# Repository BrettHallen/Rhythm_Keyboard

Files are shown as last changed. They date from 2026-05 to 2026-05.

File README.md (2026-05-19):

# Ритм Клавиатура<br>Rhythm Keyboard
Mystery post-Soviet (1992) КР80ВМ80А (Intel 8080) based machine.<br>

It has 2KB of RAM (КР537РУ10, like HM6516-9) and 6KB of ROM (three КС573РФ2, like 2716).<br>

There doesn't appear to be any factory or design marking that I've found so far.  The case is metal and is possibly custom made.  There is an expansion interface (СНП58-64, like DIN 41612) but there is no access from outside the case.<br>

It has a 5-pin DIN socket for what we assume is a cassette (магнитофон) and a very long 9-wire cable that has been cut, perhaps from some larger device that it controlled and was not possible to move.<br>

The main chips are:<br>
- КР580ВМ80А (Intel 8080A CPU)
- КР580ВВ51А  (Intel 8251 USART)
- КР580ГФ24 (Intel 8224 clock generator/driver)
- КР580ВИ53 (Intel 8253 PIT)
- 2 x КР580ВВ55А (Intel 8255 PPI)
- КР537РУ10 (HM6516-9 2KB SRAM)
- 3 x КС573РФ2 (2716 2KB EPROM)

The keyboard uses QWERTY layout for the Latin characters instead of the more usual JCUKEN layout I would associate with Soviet 8080-based machines.<br>

It also has a three digit display which is a first for me as well.<br>

## [ROMs](/ROMs)
The machine has 6KB of ROM split across three КС573РФ2 (2716) EPROMs.<br>

The ROMs are labelled "Ритм КЛАВ" which my English brain wants to translate to "Rhythm Keyboard" and have IDs N1 to N3.<br>
Two ROMs (N1 & N2) are piggybacked and the N3 ROM is piggybacked on top of the SRAM.<br>
They also have a 16-bit checksum (контрольная сумма) using the [CRC-16/IBM-SDLC](https://emn178.github.io/online-tools/crc/) (CRC-16/ISO-IEC-14443-3-B, CRC-16/X-25, CRC-B) algorithm.<br>

| ROM | Label | CRC-B | Status |
|-----|---|---|---|
| N1  | 1620  | 1620  | OK |
| N2  | B47D  | ACBB  | NOK? |
| N3  | 9719  | 9B1A  | NOK? |

## Memory Map
The A11/A12/A13 address decoding by the К555ИД7/74LS138 gives us this possible memory map.<br>

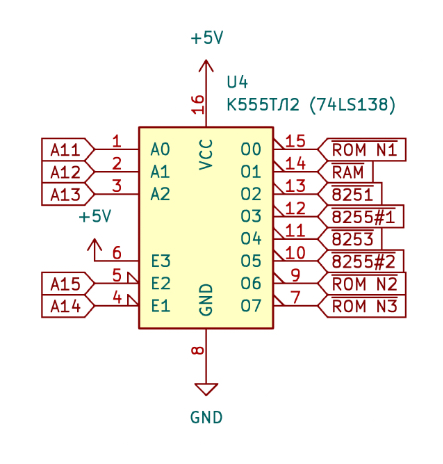
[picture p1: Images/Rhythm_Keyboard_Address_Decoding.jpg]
Address decoding


| Address Range | Device | Possible purpose |
|---|---|---|
| 0x0000–0x07FF | КС573РФ2/ROM N1 | Main program (keyboard handling, modes, display control, core logic) |
| 0x0800–0x0FFF | КР537РУ10/RAM | System variables, flags, buffers, stack, temporary data |
| 0x1000–0x17FF | КР580ВВ51А/8251 | Serial interface |
| 0x1800–0x1FFF | КР580ВВ55А/8255 #1 | Keyboard matrix |
| 0x2000–0x27FF | КР580ВИ53/8253 | Sound generation |
| 0x2800–0x2FFF | КР580ВВ55А/8255 #2 | 3-digit 7-segment display + control signals |
| 0x3000–0x37FF | КС573РФ2/ROM N2 | Sound data, waveforms, rhythm tables, or additional code |
| 0x3800–0x3FFF | КС573РФ2/ROM N3 | Extra code, lookup tables, or sequencer support |

## Bill of Materials
| IC | Soviet | Western | Purpose |
|---|---|---|---|
| IC01 | АОТ101АС | ILD74 | Two channel optocoupler |
| IC02 | КР140УД708 | LM741 | Op. amp. |
| IC03 | К554СА3 | LM311 | Comparator |
| IC04 | К555ТЛ2 | 74LS14 | Hex Schmitt trigger |
| IC05 | КР580ГФ24  | Intel 8224  | Clock generator for 8080 |
| IC06 | КР580ВМ80А | Intel 8080A | 8-bit CPU |
| IC07 | К555ИД7 | 74LS138 | 3-to-8 decoder |
| IC08 | КР1533ЛА3  | 74ALS00 | Quad 2-input NAND |
| IC09 | КР537РУ10  | HM6516 | 2KB SRAM |
| IC10 | КС573РФ2 | 2716 | 2KB EPROM |
| IC11 | КС573РФ2 | 2716 | 2KB EPROM |
| IC12 | КС573РФ2 | 2716 | 2KB EPROM |
| IC13 | КР580ВВ51А | Intel 8251  | Universal Sync/Async Receiver/Transmitter (USART) |
| IC14 | КР580ВИ53  | Intel 8253  | Programmable Interval Timer (PIT) |
| IC15 | КР580ВВ55А | Intel 8255  | Programmable Peripheral Interface (PPI) |
| IC16 | КР580ВВ55А | Intel 8255  | Programmable Peripheral Interface (PPI) |
| IC17 | K155ЛН2 | 7405 | Hex inverter |
| IC18 | K155ЛН2 | 7405 | Hex inverter |
| IC19 | K155ЛН2 | 7405 | Hex inverter |
| IC20 | K155ЛН2 | 7405 | Hex inverter |

## [Images](/Images)
Various images of the keyboard & motherboard.<br>

## Power Requirements
I'm not fully sure how the power is supposed to work at the moment.  The 8080 is a tri-voltage chip requiring ±5VDC and +12VDC.<br>

There is a КРЕН5А (7805) linear regulator inside the keyboard to generate the +5VDC.<br>

There appears to be four power wires in the cut cable.  My best guess at the moment is:
- +12V input
- КРЕН5А regulator input
- ground
- -12V input

I am guessing the -12V input at the moment, guessing that it might be used to generate the -5V required for the 8080.

Further work to be done.<br>

## Videos
- [Part 1: First look](https://youtu.be/H5vEuGISd-E)
- [Part 2: Ongoing investigations](https://youtu.be/_Wb8MkkKUJ4)

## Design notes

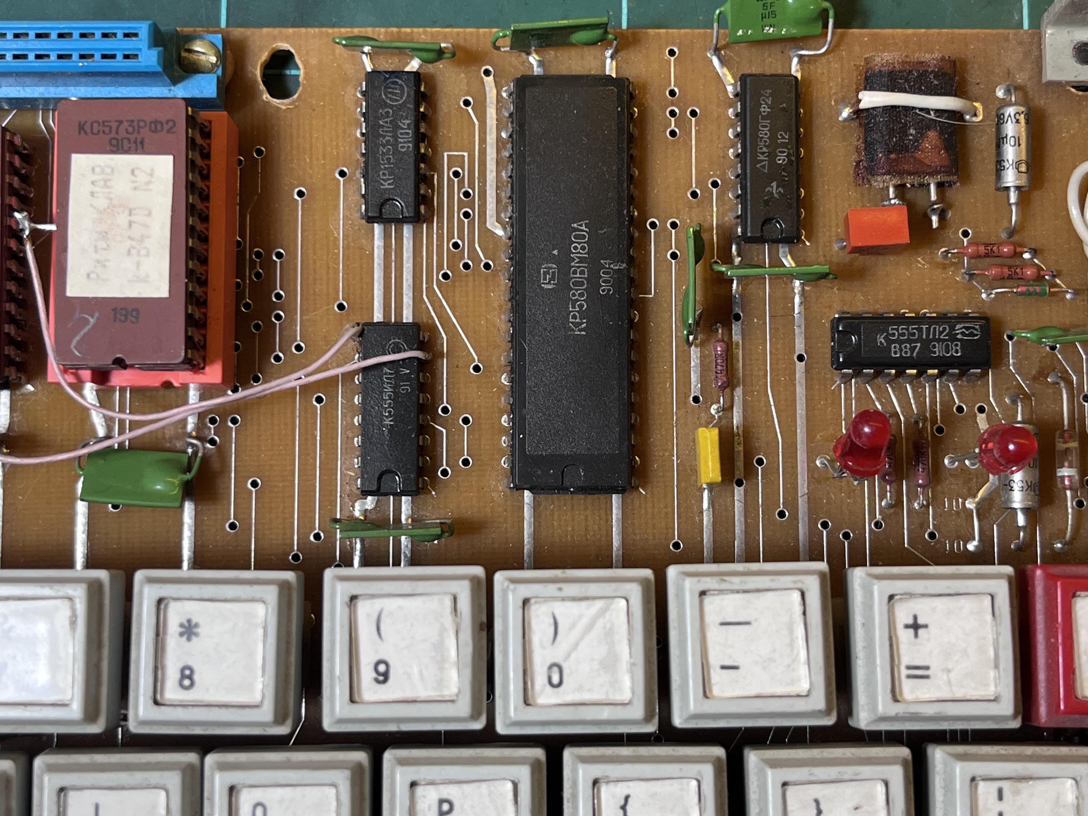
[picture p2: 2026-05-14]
Images/Rhythm_Keyboard_Motherboard03.jpeg

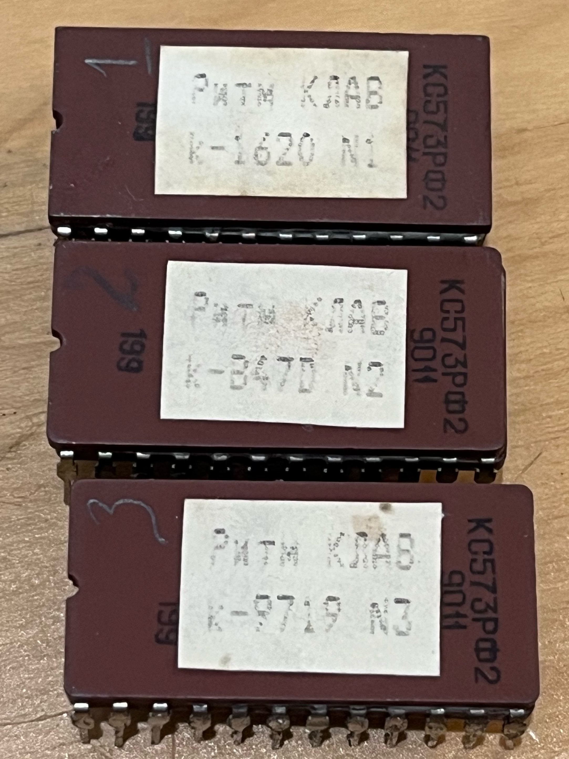
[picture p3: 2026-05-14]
Images/Rhythm_Keyboard_ROMs2.jpg

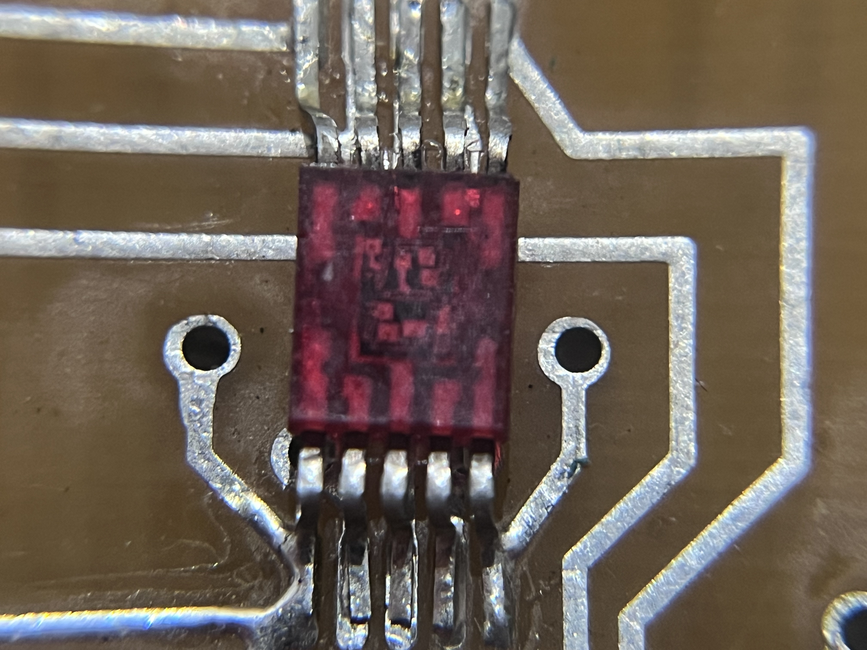
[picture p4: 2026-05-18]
Images/Rhythm_Keyboard_7seg_LED.jpeg

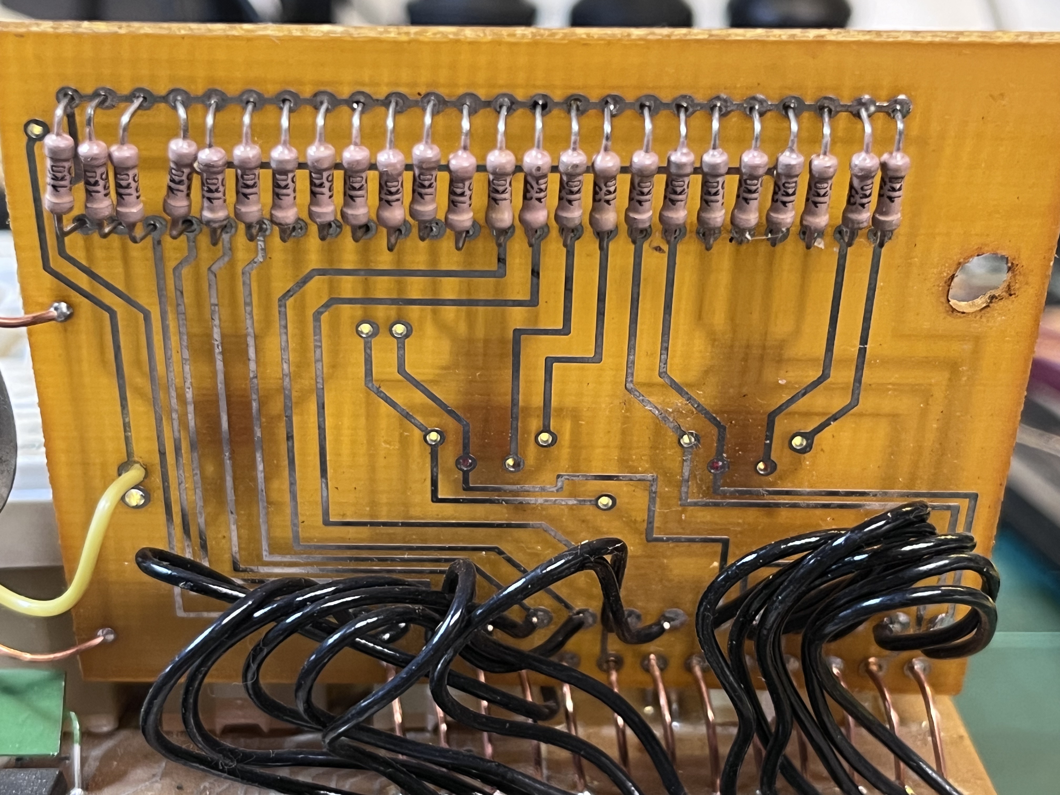
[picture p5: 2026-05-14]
Images/Rhythm_Keyboard_Motherboard01b.jpeg

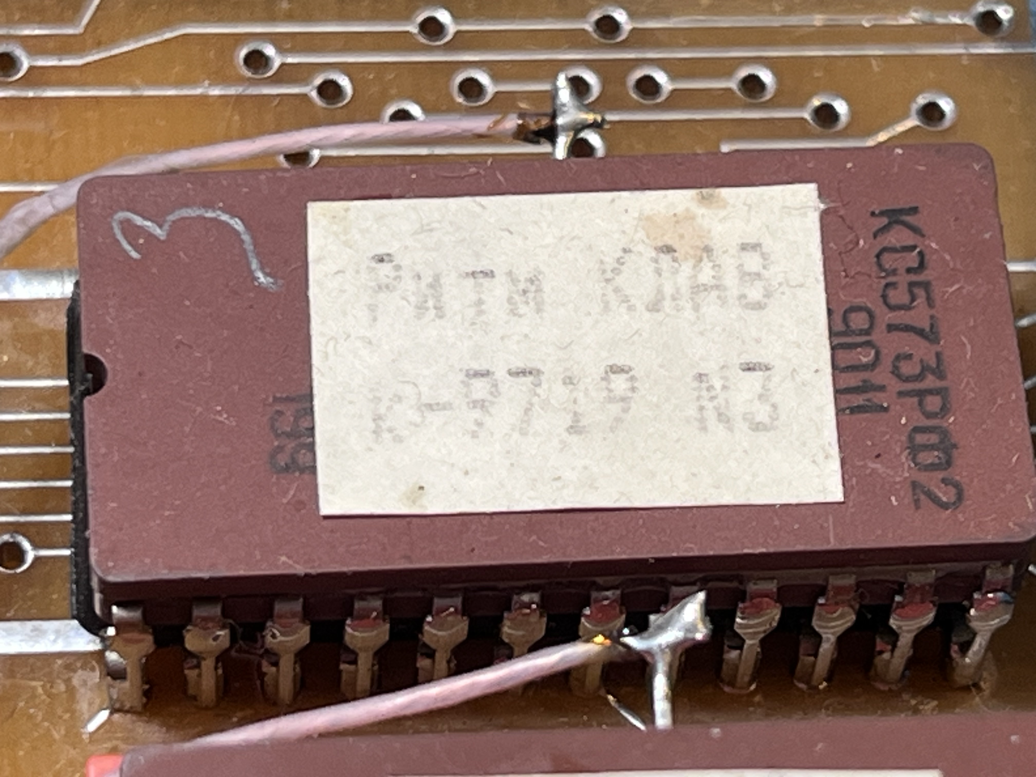
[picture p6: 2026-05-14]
Images/Rhythm_Keyboard_ROM_N3.jpeg

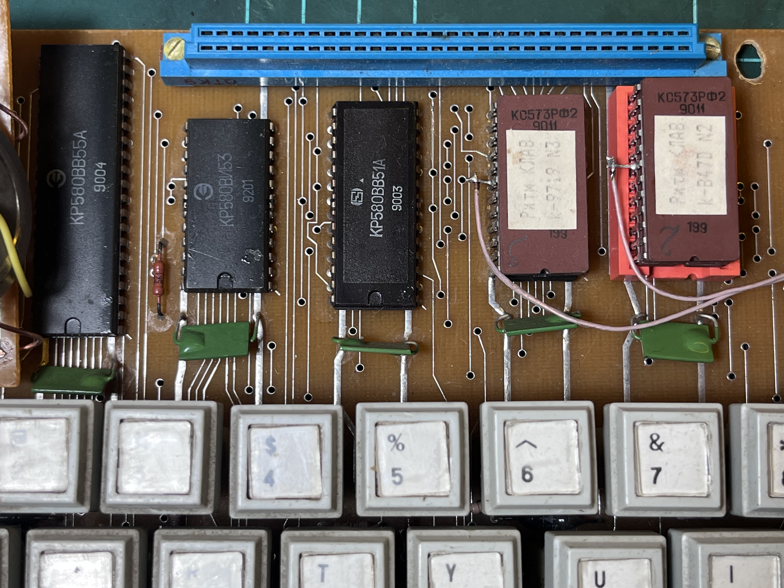
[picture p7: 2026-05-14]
Images/Rhythm_Keyboard_Motherboard02.jpeg

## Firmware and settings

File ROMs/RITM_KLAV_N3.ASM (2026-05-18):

0000 ef      		rst 5 
0001 37      		stc 
0002 92      		sub d 
0003 d2 08 38		jnc 3808h
0006 2f      		cma 
0007 3c      		inr a 
0008 fe 08   		cpi 08h
000a d2 ef 37		jnc 37efh
000d 2b      		dcx h 
000e 7c      		mov a, h 
000f b5      		ora l 
0010 c2 f2 37		jnz 37f2h
0013 21 00 00		lxi h, 0000h
0016 45      		mov b, l 
0017 55      		mov d, l 
0018 cd c6 38		call 38c6h
001b d8      		rc 
001c 09      		dad 
001d 15      		dcr d 
001e c2 18 38		jnz 3818h
0021 01 ae 06		lxi b, 06aeh
0024 09      		dad 
0025 7c      		mov a, h 
0026 1f      		rar 
0027 e6 7f   		ani 7fh
0029 57      		mov d, a 
002a 29      		dad h 
002b 7c      		mov a, h 
002c 92      		sub d 
002d 57      		mov d, a 
002e d6 09   		sui 09h
0030 32 1d 08		sta 081dh
0033 7a      		mov a, d 
0034 87      		add a 
0035 82      		add d 
0036 e6 fc   		ani fch
0038 0f      		rrc 
0039 0f      		rrc 
003a d6 05   		sui 05h
003c 32 1e 08		sta 081eh
003f b7      		ora a 
0040 c9      		ret 
0041 3a 1d 08		lda 081dh
0044 57      		mov d, a 
0045 cd d9 38		call 38d9h
0048 d8      		rc 
0049 3a 02 18		lda 1802h
004c 07      		rlc 
004d d2 45 38		jnc 3845h
0050 cd d9 38		call 38d9h
0053 d8      		rc 
0054 3a 02 18		lda 1802h
0057 07      		rlc 
0058 da 50 38		jc 3850h
005b 1e 00   		mvi e, 00h
005d cd af 38		call 38afh
0060 41      		mov b, c 
0061 cd af 38		call 38afh
0064 d8      		rc 
0065 78      		mov a, b 
0066 81      		add c 
0067 da 60 38		jc 3860h
006a ba      		cmp d 
006b da 60 38		jc 3860h
006e 2e 08   		mvi l, 08h
0070 cd 8e 38		call 388eh
0073 fe 04   		cpi 04h
0075 3f      		cmc 
0076 d8      		rc 
0077 fe 02   		cpi 02h
0079 3f      		cmc 
007a 7a      		mov a, d 
007b 1f      		rar 
007c 57      		mov d, a 
007d 79      		mov a, c 
007e 0f      		rrc 
007f d4 b3 38		cnc 38b3h
0082 cd af 38		call 38afh
0085 2d      		dcr l 
0086 c2 70 38		jnz 3870h
0089 cd d9 38		call 38d9h
008c 7a      		mov a, d 
008d c9      		ret 
008e 3a 1e 08		lda 081eh
0091 47      		mov b, a 
0092 0e 00   		mvi c, 00h
0094 3a 02 18		lda 1802h
0097 ab      		xra e 
0098 f2 a5 38		jp 38a5h
009b 7b      		mov a, e 
009c 2f      		cma 
009d 5f      		mov e, a 
009e 0c      		inr c 
009f 05      		dcr b 
00a0 c2 94 38		jnz 3894h
00a3 79      		mov a, c 
00a4 c9      		ret 
00a5 00      		nop 
00a6 00      		nop 
00a7 00      		nop 
00a8 3c      		inr a 
00a9 05      		dcr b 
00aa c2 94 38		jnz 3894h
00ad 79      		mov a, c 
00ae c9      		ret 
00af cd d9 38		call 38d9h
00b2 d8      		rc 
00b3 0e 00   		mvi c, 00h
00b5 0c      		inr c 
00b6 ca c4 38		jz 38c4h
00b9 3a 02 18		lda 1802h
00bc ab      		xra e 
00bd f2 b5 38		jp 38b5h
00c0 7b      		mov a, e 
00c1 2f      		cma 
00c2 5f      		mov e, a 
00c3 c9      		ret 
00c4 0d      		dcr c 
00c5 c9      		ret 
00c6 cd d9 38		call 38d9h
00c9 d8      		rc 
00ca 3a 02 18		lda 1802h
00cd 07      		rlc 
00ce da c6 38		jc 38c6h
00d1 1e 00   		mvi e, 00h
00d3 cd b3 38		call 38b3h
00d6 c3 b5 38		jmp 38b5h
00d9 3a 02 18		lda 1802h
00dc e6 30   		ani 30h
00de ca e3 38		jz 38e3h
00e1 b7      		ora a 
00e2 c9      		ret 
00e3 37      		stc 
00e4 c9      		ret 
00e5 3e 0b   		mvi a, 0bh
00e7 cd 3a 03		call 033ah
00ea 11 00 40		lxi d, 4000h
00ed cd 7a 39		call 397ah
00f0 21 1f 08		lxi h, 081fh
00f3 22 19 08		shld  0819h
00f6 3e 0e   		mvi a, 0eh
00f8 cd b3 34		call 34b3h
00fb cd 9d 34		call 349dh
00fe b9      		cmp c 
00ff ca 0b 39		jz 390bh
0102 79      		mov a, c 
0103 fe 01   		cpi 01h
0105 ca 38 39		jz 3938h
0108 c3 f0 38		jmp 38f0h
010b 3e 0e   		mvi a, 0eh
010d cd b3 34		call 34b3h
0110 cd 9d 34		call 349dh
0113 b9      		cmp c 
0114 c2 02 39		jnz 3902h
0117 2a 19 08		lhld 0819h
011a 7e      		mov a, m 
011b cd b3 34		call 34b3h
011e cd 9d 34		call 349dh
0121 b9      		cmp c 
0122 c2 02 39		jnz 3902h
0125 2a 19 08		lhld 0819h
0128 7e      		mov a, m 
0129 fe 0f   		cpi 0fh
012b ca 35 39		jz 3935h
012e 23      		inx h 
012f 22 19 08		shld  0819h
0132 c3 17 39		jmp 3917h
0135 c3 03 00		jmp 0003h
0138 cd 94 03		call 0394h
013b fe 00   		cpi 00h
013d ca 38 39		jz 3938h
0140 3e 02   		mvi a, 02h
0142 cd 3a 03		call 033ah
0145 cd 94 03		call 0394h
0148 fe 00   		cpi 00h
014a c2 45 39		jnz 3945h
014d c3 03 00		jmp 0003h
0150 f1      		pop psw 
0151 c3 a5 04		jmp 04a5h
0154 f1      		pop psw 
0155 c3 45 05		jmp 0545h
0158 f5      		push psw 
0159 cd 77 07		call 0777h
015c e6 20   		ani 20h
015e c2 54 39		jnz 3954h
0161 f1      		pop psw 
0162 cd c2 07		call 07c2h
0165 3e 0e   		mvi a, 0eh
0167 cd 3a 03		call 033ah
016a 11 ff 05		lxi d, 05ffh
016d cd 7a 39		call 397ah
0170 c3 6e 05		jmp 056eh
0173 11 ff 17		lxi d, 17ffh
0176 cd 7a 39		call 397ah
0179 c9      		ret 
017a 1b      		dcx d 
017b 7a      		mov a, d 
017c b3      		ora e 
017d c2 7a 39		jnz 397ah
0180 c9      		ret 
0181 11 ff df		lxi d, dfffh
0184 cd 7a 39		call 397ah
0187 c9      		ret 
0188 11 ff af		lxi d, afffh
018b cd 7a 39		call 397ah
018e c9      		ret 
018f f5      		push psw 
0190 c5      		push b 
0191 d5      		push d 
0192 e5      		push h 
0193 3a 12 08		lda 0812h
0196 e6 fd   		ani fdh
0198 32 12 08		sta 0812h
019b 32 02 18		sta 1802h
019e cd 81 39		call 3981h
01a1 3a 12 08		lda 0812h
01a4 f6 02   		ori 02h
01a6 32 12 08		sta 0812h
01a9 32 02 18		sta 1802h
01ac cd 88 39		call 3988h
01af e1      		pop h 
01b0 d1      		pop d 
01b1 c1      		pop b 
01b2 f1      		pop psw 
01b3 c9      		ret 
01b4 31 00 10		lxi sp, 1000h
01b7 f3      		di 
01b8 3e 98   		mvi a, 98h
01ba 32 03 18		sta 1803h
01bd cd a1 3a		call 3aa1h
01c0 21 f7 09		lxi h, 09f7h
01c3 11 a0 0f		lxi d, 0fa0h
01c6 cd bc 3a		call 3abch
01c9 cd a7 3a		call 3aa7h
01cc 21 f7 09		lxi h, 09f7h
01cf 11 a0 0f		lxi d, 0fa0h
01d2 cd bc 3a		call 3abch
01d5 cd a7 3a		call 3aa7h
01d8 21 77 07		lxi h, 0777h
01db 11 40 1f		lxi d, 1f40h
01de cd bc 3a		call 3abch
01e1 cd ae 3a		call 3aaeh
01e4 21 77 07		lxi h, 0777h
01e7 11 40 1f		lxi d, 1f40h
01ea cd bc 3a		call 3abch
01ed cd ae 3a		call 3aaeh
01f0 21 77 07		lxi h, 0777h
01f3 11 40 1f		lxi d, 1f40h
01f6 cd bc 3a		call 3abch
01f9 21 e9 07		lxi h, 07e9h
01fc 11 40 1f		lxi d, 1f40h
01ff cd bc 3a		call 3abch
0202 21 77 07		lxi h, 0777h
0205 11 40 1f		lxi d, 1f40h
0208 cd bc 3a		call 3abch
020b 21 a7 06		lxi h, 06a7h
020e 11 40 1f		lxi d, 1f40h
0211 cd bc 3a		call 3abch
0214 21 ed 05		lxi h, 05edh
0217 11 40 1f		lxi d, 1f40h
021a cd bc 3a		call 3abch
021d cd ae 3a		call 3aaeh
0220 21 ed 05		lxi h, 05edh
0223 11 40 1f		lxi d, 1f40h
0226 cd bc 3a		call 3abch
0229 cd ae 3a		call 3aaeh
022c 21 ed 05		lxi h, 05edh
022f 11 40 1f		lxi d, 1f40h
0232 cd bc 3a		call 3abch
0235 21 47 06		lxi h, 0647h
0238 11 40 1f		lxi d, 1f40h
023b cd bc 3a		call 3abch
023e 21 ed 05		lxi h, 05edh
0241 11 40 1f		lxi d, 1f40h
0244 cd bc 3a		call 3abch
0247 21 98 05		lxi h, 0598h
024a 11 40 1f		lxi d, 1f40h
024d cd bc 3a		call 3abch
0250 21 fc 04		lxi h, 04fch
0253 11 40 1f		lxi d, 1f40h
0256 cd bc 3a		call 3abch
0259 cd ae 3a		call 3aaeh
025c 21 fc 04		lxi h, 04fch
025f 11 40 1f		lxi d, 1f40h
0262 cd bc 3a		call 3abch
0265 cd ae 3a		call 3aaeh
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

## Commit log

2026-05-16 Initial work
    [Interface.kicad_sch, Memory.kicad_sch, Schematic_Scraps.kicad_pcb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]
2026-05-17 Analysis progress
    [Interface.kicad_sch, Memory.kicad_sch, Schematic_Scraps.kicad_sch]
2026-05-17 Reverse engineering progress
    [Audio.kicad_sch, Display.kicad_sch, Interface.kicad_sch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]
2026-05-17 Further reverse engineering progress
    [Audio.kicad_sch, Display.kicad_sch, Interface.kicad_sch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]
2026-05-18 Reverse engineering updates
    [Audio.kicad_sch, Interface.kicad_sch]
2026-05-19 19-May reverse engineering progress
    [Audio.kicad_sch, Display.kicad_sch, Interface.kicad_sch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]
2026-05-19 Added SERIAL_CLOCK source (8224)
    [Schematic_Scraps.kicad_sch]
2026-05-19 Turning into a real schematic ...
    [Audio.kicad_sch, Display.kicad_sch, Interface.kicad_sch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]
